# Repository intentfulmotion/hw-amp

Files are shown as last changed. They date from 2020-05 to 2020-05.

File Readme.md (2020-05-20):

# Amp Smart Lighting Controller

## Description

An ESP32 based lighting controller designed for lighting up bicycles, scooters, skateboards, and other micromobility.

## Features

* 3 axis, low noise, low zero-g error accelerometer (LIS2DHH12TR)
* Power supervisor + 2A regulated 3.3V output for long lengths of LEDs (WS2812B style or APA102 style leds)
* USB C Power Delivery compatible charging (does not implement the USB PD spec for higher charging rates)
* One button input connected to the ESP32 through the power supervisor
* One WS2812B LED for status onput
* LiPo charging @ 1A with charging and done charging indications
* Pin connections for LiPo battery with temperature sensing (2000 mAh recommended, 1000 mAh doable)
* MessagePack configuration for lighting strip setup
* Bluetooth LE for signaling indicators, brakes
* Customizable and scriptable lighting modes
* Over the Air updates over WiFi
* BLE Mesh (will be enabled in a future firmware update)
* Re-programmable over 6 pin programming header or via USB C so that you can load up your own firmware
* 4 channels of output (power + signal) for LED strips using JST-PH connectors (Qwiic connectors with different pin out)

## More Information

You can purchase a pre-assembled unit from the [Amp website](https://ridewithamp.com/store/amp-beta-0.5)

Alternatively, you can assemble a PCB with your preferred board manufacturer using the Gerbers provided in this repository or modify the project to your needs using the KiCad 5 project files.

## License

[Strong Reciprocal CERN Open Hardware License v2](License.md)

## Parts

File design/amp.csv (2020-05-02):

Id | Designator | Package | Quantity | Designation | Supplier and ref
1 | U1 | ESP32-WROOM-32 | 1 | ESP32-WROOM-32D
2 | R11,R10,R1,R13,R6,R7 | RC0402FR-0710KL,RESC1005X40N | 6 | AT0402FRE0710KL
3 | J4 | SolderWirePad_1x03_P3.175mm_Drill0.8mm | 1 | Conn_01x03_Female
4 | R12 | RESC1005X40N | 1 | RR0510P-102-D
5 | IC2 | SON50P300X300X100-11N-D | 1 | MCP73833-FCI_MF
6 | C16,C7,C6,C11 | CAPC1608X90N | 4 | TMK107BJ105KA-T
7 | IC4 | SON95P300X300X100-7N-D | 1 | LD39200PU33R
8 | IC3 | SON50P200X300X80-12N-D | 1 | STM6601CQ2BDM6F
9 | C12,C4,C15,C10,C5,C9,C2,C1 | CAPC1005X55N | 8 | GRM155R61H104KE14D
10 | J1 | GCT_USB4105-GF-A | 1 | USB4105-GF-A
11 | J6,J2,J7,J3 | JST_SM04B-SRSS-TB(LF)(SN) | 4 | SM04B-SRSS-TB(LF)(SN)
12 | R9 | RESC1005X37N | 1 | AC0402FR-13100KL-SamacSys_Parts
13 | R8 | RESC1608X55N | 1 | RC0603FR-101K2L
14 | U2 | LGA-12_2x2mm_P0.5mm | 1 | LIS2HH12
15 | R5 | RESC1005X35N | 1 | CRCW0402140RFKEDC
16 | R4 | RESC1005X35N | 1 | CRCW040222K6FKEDC
17 | J5 | PinHeader_2x03_P1.27mm_Vertical | 1 | Conn_02x03_Odd_Even
18 | FID2,FID1 | Fiducial_0.5mm_Mask1.5mm | 2 | Fiducial
19 | R3,R2 | RESC0603X26N | 2 | RC0201FR-075K1L
20 | S1 | EVQQ2 | 1 | EVQ-Q2U03W
21 | D2 | SOD2513X110N | 1 | BAT60AE6327HTSA1
22 | IC1 | QFN50P400X400X80-25N-D | 1 | CP2102N-A02-GQFN24R
23 | Q1,Q2 | SOT95P230X110-3N | 2 | PMBT2222,215
24 | Q3 | SOT95P237X112-3N | 1 | Si2347DS-T1-GE3
25 | D1 | LED_WS2812B_PLCC4_5.0x5.0mm_P3.2mm | 1 | WS2812B
26 | H4,H3,H2,H1 | MountingHole_3mm | 4 | MountingHole
27 | C14,C13,C8,C3 | CAPC1608X95N | 4 | GRM188R61A106KE69D

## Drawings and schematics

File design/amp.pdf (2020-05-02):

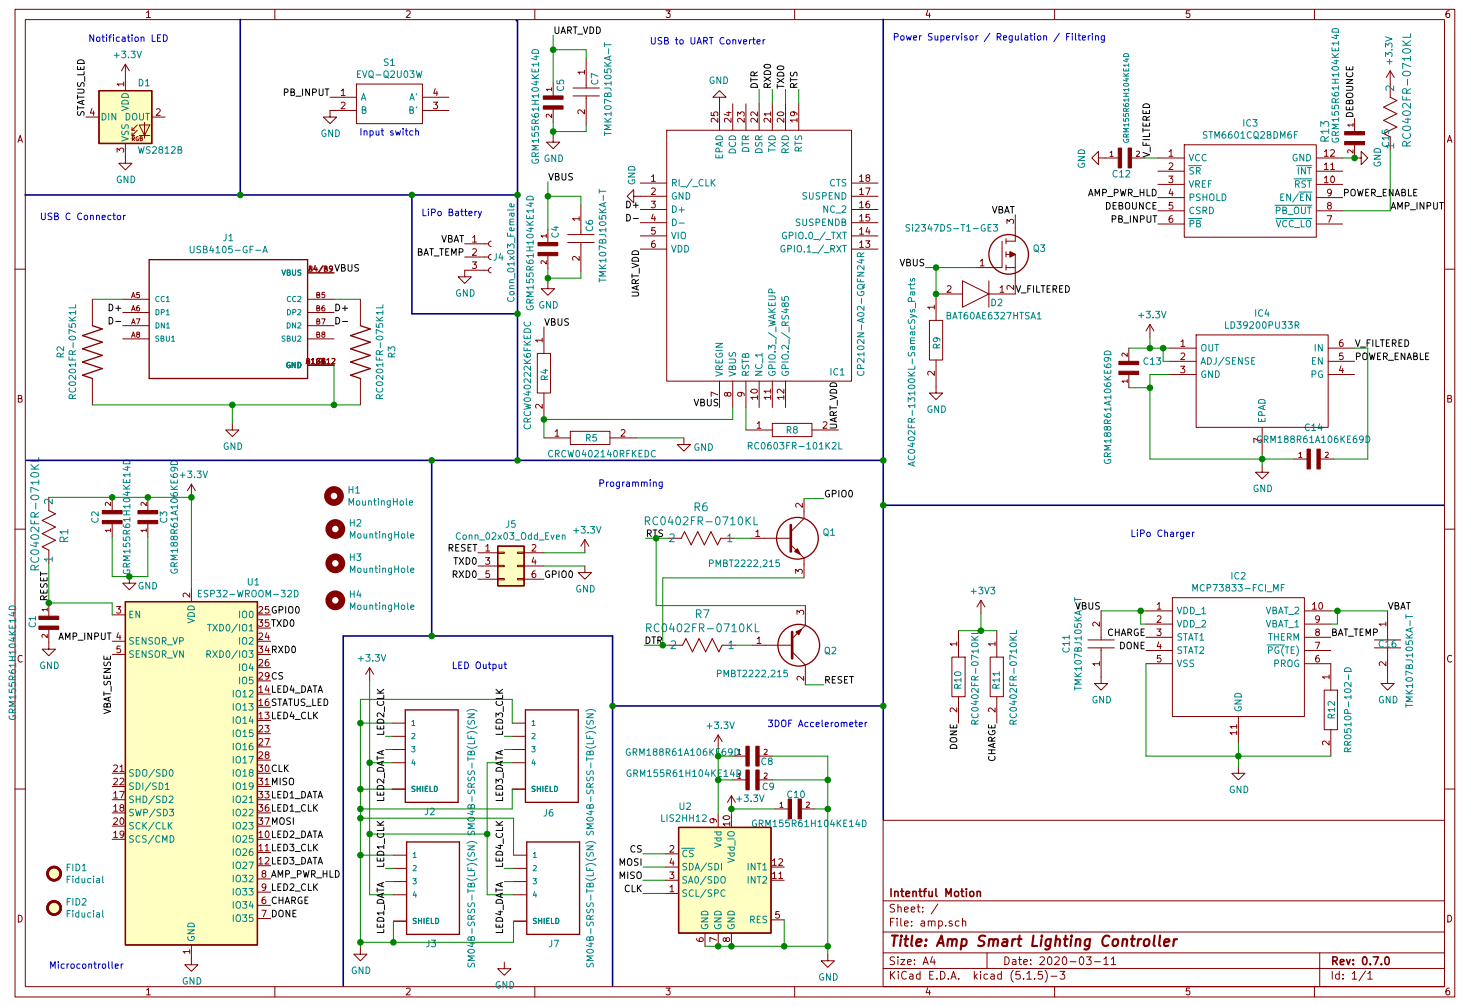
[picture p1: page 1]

LiPo Battery Notification LED

USB to UART Converter

Power Supervisor / Regulation / Filtering

3 DIN 4 D1WS2812B RI_/_CLK 1 NC_1 10 GPIO.3_/_WAKEUP 11 GPIO.2_/_RS485 12 GPIO.1_/_RXT 13 GPIO.0_/_TXT 14 SUSPENDB 15 NC_2 16 SUSPEND 17 CTS 18 RTS 19 GND 2 RXD 20 TXD 21 DSR 22 DTR 23 DCD 24 EPAD 25 D+ 3 D- 4 VIO 5 VDD 6 VREGIN

1 2 C6 TMK107BJ105KA-T VDD_1 1 VDD_2 2 STAT1 3 STAT2 4 VSS 5 GND 11 VBAT_2 10 VBAT_1 9 THERM 8 PG(TE) 7 PROG 6

2 SCK/CLK 20 SDO/SD0 21 SDI/SD1 22

Intentful Motion
File: amp.sch Sheet: /
Id: 1/1 Title: Amp Smart Lighting Controller

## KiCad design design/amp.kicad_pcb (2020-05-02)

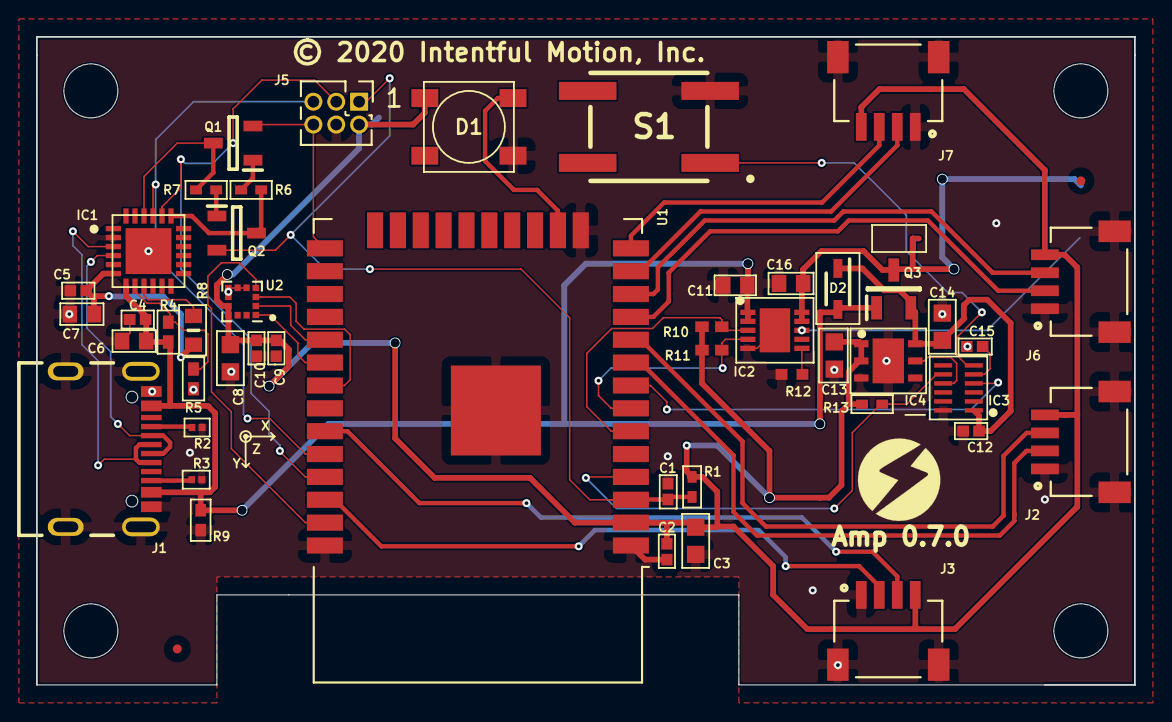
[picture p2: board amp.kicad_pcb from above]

Board: 2 copper layers, 61.0 x 36.0 mm, 54 parts (1 on the bottom side), 42 nets.

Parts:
C1, C2, C4, C5, C9, C10, C12, C15: GRM155R61H104KE14D; CAPC1005X55N
C3, C8, C13, C14: GRM188R61A106KE69D; CAPC1608X95N
C6, C7, C11, C16: TMK107BJ105KA-T; CAPC1608X90N
D1: WS2812B; LED_WS2812B_PLCC4_5.0x5.0mm_P3.2mm
D2: BAT60AE6327HTSA1; SOD2513X110N
FID1, FID2: Fiducial; Fiducial_0.5mm_Mask1.5mm
H1, H2, H3, H4: MountingHole; MountingHole_3mm
IC1: CP2102N-A02-GQFN24R; QFN50P400X400X80-25N-D
IC2: MCP73833-FCI_MF; SON50P300X300X100-11N-D
IC3: STM6601CQ2BDM6F; SON50P200X300X80-12N-D
IC4: LD39200PU33R; SON95P300X300X100-7N-D
J1: USB4105-GF-A; GCT_USB4105-GF-A
J2, J3, J6, J7: SM04B-SRSS-TB(LF)(SN); JST_SM04B-SRSS-TB(LF)(SN)
J4: Conn_01x03_Female; SolderWirePad_1x03_P3.175mm_Drill0.8mm
J5: Conn_02x03_Odd_Even; PinHeader_2x03_P1.27mm_Vertical
Q1, Q2: PMBT2222,215; SOT95P230X110-3N
Q3: Si2347DS-T1-GE3; SOT95P237X112-3N
R1, R6, R7, R13: RC0402FR-0710KL
R2, R3: RC0201FR-075K1L; RESC0603X26N
R4: CRCW040222K6FKEDC; RESC1005X35N
R5: CRCW0402140RFKEDC; RESC1005X35N
R8: RC0603FR-101K2L; RESC1608X55N
R9: AC0402FR-13100KL-SamacSys_Parts; RESC1005X37N
R10, R11: RC0402FR-0710KL; RESC1005X40N
R12: RR0510P-102-D; RESC1005X40N
S1: EVQ-Q2U03W; EVQQ2
U1: ESP32-WROOM-32D; ESP32-WROOM-32
U2: LIS2HH12; LGA-12_2x2mm_P0.5mm

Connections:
+3V3: C2.2, C3.2, C8.1, C9.1, C10.1, C13.2, D1.1, IC4.1, IC4.2, J2.4, J3.4, J5.2, J6.4, J7.4, R1.2, R10.1, R11.1, R13.2, U1.2, U2.9, U2.10
/AMP_INPUT: IC3.8, R13.1, U1.4
/AMP_PWR_HLD: IC3.4, U1.8
/BAT_TEMP: IC2.8, J4.2
/CHARGE: IC2.3, R11.2, U1.6
/CLK: U1.30, U2.1
/CS: U1.29, U2.2
/D+: IC1.3, J1.A6, J1.B6
/D-: IC1.4, J1.A7, J1.B7
/DEBOUNCE: C15.1, IC3.5
/DONE: IC2.4, R10.2, U1.7
/DTR: IC1.22, Q1.3, R7.2
/GPIO0: J5.6, Q1.2, U1.25
/LED1_CLK: J3.2, U1.36
/LED1_DATA: J3.3, U1.33
/LED2_CLK: J2.2, U1.9
/LED2_DATA: J2.3, U1.10
/LED3_CLK: J6.2, U1.11
/LED3_DATA: J6.3, U1.12
/LED4_CLK: J7.2, U1.13
/LED4_DATA: J7.3, U1.14
/MISO: U1.31, U2.3
/MOSI: U1.37, U2.4
/PB_INPUT: IC3.6, S1.1
/POWER_ENABLE: IC3.9, IC4.5
/RESET: C1.1, J5.1, Q2.2, R1.1, U1.3
/RTS: IC1.19, Q2.3, R6.2
/RXD0: IC1.21, J5.5, U1.34
/STATUS_LED: D1.4, U1.16
/TXD0: IC1.20, J5.3, U1.35
/UART_VDD: C5.1, C7.1, IC1.6, R8.2
/VBAT: C16.1, IC2.9, IC2.10, J4.1, Q3.3
/VBUS: C4.1, C6.1, C11.2, D2.2, IC1.7, IC2.1, IC2.2, J1.A4/B9, J1.B4/A9, Q3.1, R4.1, R9.1
/V_FILTERED: C12.2, C14.2, D2.1, IC3.1, IC4.6, Q3.2
GND: C1.2, C2.1, C3.1, C4.2, C5.2, C6.2, C7.2, C8.2, C9.2, C10.2, C11.1, C12.1, C13.1, C14.1, C15.2, C16.2, D1.3, IC1.2, IC1.25, IC2.5, IC2.11, IC3.12, IC4.3, IC4.7, J1.A1/B12, J1.B1/A12, J1.G1, J1.G2, J1.G3, J1.G4, J2.1, J2.S1, J2.S2, J3.1, J3.S1, J3.S2, J4.3, J5.4, J6.1, J6.S1, J6.S2, J7.1, J7.S1, J7.S2, R2.1, R3.2, R5.2, R9.2, R12.2, S1.2, U1.1, U1.15, U1.38, U1.39, U2.5, U2.6, U2.7, U2.8
unnamed: IC1.8, R4.2, R5.1
unnamed: IC1.9, R8.1
unnamed: IC2.6, R12.1
unnamed: J1.A5, R2.2
unnamed: J1.B5, R3.1
unnamed: Q1.1, R6.1
unnamed: Q2.1, R7.1

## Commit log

2020-03-28 added led info
2020-03-28 added info about led channel output
2020-03-30 updated to new USB connector. Flipped status led and input button
    [amp-B_Cu.gbr, amp-B_Mask.gbr, amp-B_SilkS.gbr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]
2020-05-01 Fixes for CP2102N and LIS2DH12 circuitry. Swapped Futaba connectors for Qwiic style JST-PH connectors
    [amp-B_Cu.gbr, amp-B_Mask.gbr, amp-B_SilkS.gbr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]
2020-05-02 moved components to fit all connectors on the top layer
    [amp-B_Cu.gbr, amp-B_Mask.gbr, amp-B_SilkS.gbr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]
2020-05-02 removed bicolor led for charge and done. inputs redirected to ESP32
    [amp-B_Cu.gbr, amp-B_Mask.gbr, amp-B_SilkS.gbr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]
2020-05-02 added silkscreen logo to the front
    [amp-B_Cu.gbr, amp-B_Mask.gbr, amp-B_SilkS.gbr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]
2020-05-02 added bom
    [amp.csv]
2020-05-02 fixed BOM listing for CP2102N RSTb resistors
    [amp.csv]
2020-05-02 fixed schematic listing for R4 resistor
2020-05-02 fixed schematic version number
2020-05-02 Swapped out DIO5158 for MCP83733 (part shortage)
    [amp-B_Cu.gbr, amp-B_Mask.gbr, amp-B_SilkS.gbr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]
2020-05-02 extraneous net
    [amp-B_Cu.gbr, amp-B_Mask.gbr, amp-B_SilkS.gbr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]
2020-05-02 update board layout
    [amp.kicad_pcb]

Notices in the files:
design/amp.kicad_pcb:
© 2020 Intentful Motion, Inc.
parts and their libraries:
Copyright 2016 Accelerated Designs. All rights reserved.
